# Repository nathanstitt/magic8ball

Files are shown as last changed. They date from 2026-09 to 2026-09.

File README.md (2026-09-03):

# Magic 8 Ball

Firmware for a physical, voice-activated **Magic 8 Ball** built on a round AMOLED
ESP32-S3 board. Ask it a question out loud — _"Magic 8 Ball, will it rain
tomorrow?"_ — and a glowing blue answer triangle rises from dark liquid, jitters
into place, blooms, and reveals an answer. The answer is generated live by
**Google Gemini** (which transcribes your spoken question and replies in five
words or fewer, in the oracular voice of a Magic 8 Ball). Tap or shake for a
classic random answer instead.

Everything is drawn by a **custom software renderer** — no LVGL, no GPU — a pure
RGB565 pixel pipeline running on the ESP32-S3.

## Hardware

- **Board:** [Waveshare ESP32-S3-Touch-AMOLED-1.75](https://www.waveshare.com/esp32-s3-touch-amoled-1.75.htm)
  ([documentation](https://docs.waveshare.com/ESP32-S3-Touch-AMOLED-1.75) — schematic, pinout, demos)
  - 466×466 round AMOLED, **CO5300** panel driven over QSPI
  - **QMI8658** 6-axis IMU (shake to ask)
  - **CST9217** capacitive touch (tap to ask, hold to factory-reset)
  - On-board microphone (**ES7210** codec) for wake word + question capture
  - **ES8311** codec + amplifier driving a speaker for the answer chime
  - **AXP2101** PMIC for power management, battery charging and fuel gauge
- **Microcontroller:** ESP32-S3 (dual-core Xtensa LX7, 8 MB PSRAM, 16 MB flash)

## Features

- **Voice-activated answers** — say the **"Magic 8 Ball"** wake word
  (on-device [microWakeWord](https://github.com/nathanstitt/micro_wake_word_standalone)
  model, ~61 KB), ask a question, and Gemini answers it in ≤5 words.
- **On-device wake-word detection** — runs locally; only the recorded question is
  sent to the cloud, and only after the wake word fires.
- **Record-until-silence** — an energy VAD ends recording when you stop talking,
  so asks are as short as your question.
- **One-shot multimodal Gemini call** — the recorded audio (WAV) and the persona
  prompt go to Gemini's `generateContent` in a single HTTPS request; Gemini both
  transcribes and answers.
- **Graceful fallback** — no Wi-Fi, no API key, or any API error falls back to one
  of the 20 classic Magic 8 Ball answers, so the ball always responds.
- **Tap & shake** — a screen tap or an IMU shake gives a classic random answer.
- **Animated reveal** — a 3-D triangle rises from the liquid, wobbles, blooms its
  glow, and the answer text fades in. The rise overlaps the Gemini round-trip
  (starts mid-wait, holds with a pulsing glow) to hide the latency.
- **Listening / thinking cues** — a white flitting starfield while it listens,
  switching to faster blue stars while Gemini is thinking.
- **Smart text layout** — a top-heavy best-fit word wrap fits answers to the
  apex-down triangle (more words on the wider upper rows).
- **Wi-Fi provisioning portal** — a captive-portal setup AP collects Wi-Fi
  credentials and the Gemini API key (stored in NVS); reachable at
  `http://magic8ball.local/` on the LAN, which also accepts custom messages via POST.
- **Hold-to-reset gesture** — hold the screen during normal use to clear saved
  Wi-Fi + API key and reboot into the setup AP (re-provision without a cable).
- **Answer chime** — three short blips play through the speaker as the answer
  blooms into view. Synthesized procedurally at boot (no audio asset): each blip
  glides down in pitch while the three step up, kept inside ~490–890 Hz because the
  ball's micro speaker has almost no output below ~450 Hz.
- **Power management** — sleeps the panel when idle, and runs a low-battery
  watchdog that powers the board down before the cell is damaged. Three guards must
  agree before it cuts power (boot grace period, a consecutive-low-reading streak,
  and a VBAT cross-check), because the fuel gauge reads a plausible-looking 0 for
  the first seconds after power-on.
- **Named on the network** — requests `magic8ball` as its DHCP hostname and
  advertises the same name over mDNS, so it is reachable at `magic8ball.local`
  (and often just `magic8ball`) rather than by a bare IP.

## Architecture (`main/`)

- `config.h` — every tunable (geometry, timing, colors, animation rates, mic gain).
  No magic literals elsewhere.
- `gfx/` — pure pixel primitives: framebuffer, color (RGB565 + blend), draw
  (rasterizer, triangle gradient + glow), text (Montserrat Bold). Host-testable.
- `scene/` — pure C logic: state machine
  (IDLE→SHAKING→TUMBLING→LOCKING→SHOWING→DISMISSING→SLEEP), animation, answers,
  the energy VAD, the listen FSM, and the bloop synthesizer. Host-testable.
- `render/` — `pyramid.cpp` (the 3-D triangle + glow, the only glm user), `fx.cpp`
  (background + starfield), `render.cpp` (compositor + text wrap).
- `hal/` — board drivers: display (CO5300), IMU, touch, mic, wake word, recorder,
  speaker (ES8311), power (AXP2101). Never compiled in host tests.
- `net/` — Wi-Fi (STA-with-AP-fallback), captive-portal provisioning, HTTP server,
  mDNS, the Gemini client, and the WAV/base64 helpers.
- `app_main.cpp` — dual-core split: core 0 = logic/events/voice, core 1 = render+flush.

The renderer does a full redraw each frame. The background is precomputed once and
memcpy'd per frame; identical scenes are skipped, so idle/showing cost nothing.

## Performance

The renderer is CPU-only (no GPU) and pushes the full 466×466 round panel over QSPI
every frame. Measured on the device during the answer animation
(build with `-DDEBUG_FPS` and `-DDEBUG_FLUSH_PROFILE` to log this):

| Phase | Frame rate | Render | Flush  |
|---|---:|---:|---:|
| Answer animation | ~12–16 fps | ~28–36 ms | ~32–35 ms |
| Idle / showing | ~0 (static frames skipped) | — | — |

- The **hard floor is the ~23 ms QSPI transfer** for one full frame; the flush
  measures ~32–35 ms including the byte-swap pipelined under DMA.
- Identical scenes are skipped via a `memcmp`, so IDLE and SHOWING render nothing —
  the AMOLED just holds the last flushed frame and the CPU stays idle.
- The animation only runs during SHAKING→TUMBLING→LOCKING; the expensive glow is
  deferred to the lock/bloom so the rise stays smooth.

Getting here took a dedicated optimization pass: rendering directly in the panel's
byte order (eliminating a 33 ms per-frame byte-swap), caching the circle-clip row
spans (31 ms → 5.5 ms), incremental edge functions + a ramp LUT in the triangle
gradient (135 ms → 57 ms), and flushing in cache-line-aligned strips with the
byte-swap pipelined under DMA.

## Enclosure

The 3-D printed enclosure lives in [`cad/`](cad/), designed in
[FreeCAD](https://www.freecad.org):

| File | What it is |
|---|---|
| `magic-8-ball.FCStd` | FreeCAD source — edit this |
| `magic-8-ball-Ball.stl` | The ball itself, 70 × 69.5 × 65 mm |
| `magic-8-ball-Base.stl` | The stand the ball sits in, 54 × 56 × 11 mm |

The STLs are exports of the FreeCAD document; regenerate them from the `.FCStd`
after any change rather than editing the meshes directly.

## Build / flash / test

Requires **ESP-IDF v5.5**. Source the toolchain first:

```bash
export IDF_PATH=/path/to/esp-idf-5.5
. "$IDF_PATH/export.sh"
```

**Firmware** (repo root, target esp32s3):

```bash
idf.py build
idf.py -p <PORT> flash monitor
```

The first configure needs network access (it fetches the Waveshare BSP, glm, and
the wake-word component).

**Host tests** (`host_test/`, linux target — runs the pure `gfx/`, `scene/`,
`render/`, and `net/` helpers under Unity):

```bash
cd host_test
idf.py build
printf '\n*\n' | ./build/magic8ball_host_test.elf
```

## First-time setup

1. Flash the firmware. On first boot (no saved credentials) the device starts a
   setup Wi-Fi AP named **`Magic-8-Ball-Setup`**.
2. Join that network; the captive portal opens. Enter your Wi-Fi name/password and
   your **Gemini API key** (from [Google AI Studio](https://aistudio.google.com)).
3. The device reboots, connects, and shows its IP. Say **"Magic 8 Ball"** and ask
   away.

To re-provision later, **hold the screen** during normal use until the reset
countdown completes — it clears the saved Wi-Fi + key and returns to the setup AP.

## Changing the wake word

The wake word is an on-device [microWakeWord](https://github.com/nathanstitt/micro_wake_word_standalone)
TFLite model embedded in the firmware (`main/hal/<phrase>_model.h`, wired up in
`main/hal/wakeword.cpp`). Swapping it is a two-part job:

**Train + install in one command** (local, Apple-Silicon GPU, no Google Colab):

```bash
cd wakeword-train
./make-wakeword.sh "Hey Oracle" --phonetic "hey or-uhkul" --install
```

That synthesizes samples with Piper TTS, augments + trains on MPS, exports the
quantized `.tflite`, wires it into `wakeword.cpp`, and builds the firmware. Then
`idf.py -p <PORT> flash monitor`, say the phrase, and tune `WW_PROBABILITY_CUTOFF`
on-device if needed. The `wakeword-train/` dir is gitignored; see its README for the
step-by-step scripts and the shared-dataset caveat (~33 GB, downloaded once).

To install a model you already have (community or pre-trained):

```bash
scripts/install-wake-word.sh <model.tflite> <model.json> "Phrase"
```

This generates the C header, wires the 4 tuning constants + the model symbol/label
into `wakeword.cpp`, and removes the old model.

## Notes

- The renderer never calls LVGL. The Waveshare BSP pulls LVGL in transitively as a
  build dependency, but our code uses a narrow software RGB565 pipeline.
- The wake-word component is GPLv3 (a standalone ESPHome-derived port); see
  `main/idf_component.yml`.

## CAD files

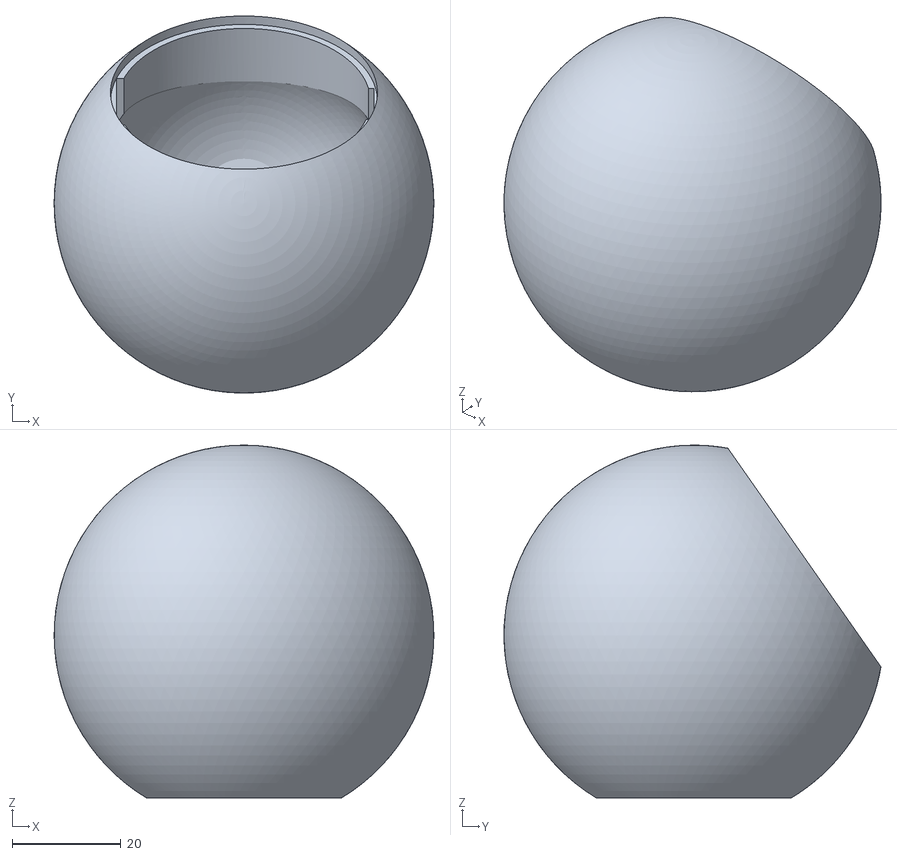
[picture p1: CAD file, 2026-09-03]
cad/magic-8-ball-Ball.stl
70.0 x 69.5 x 65.0

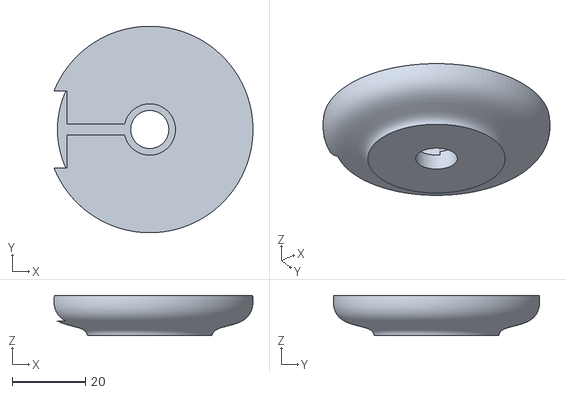
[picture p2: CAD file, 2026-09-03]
cad/magic-8-ball-Base.stl
54.2 x 56.2 x 11.0

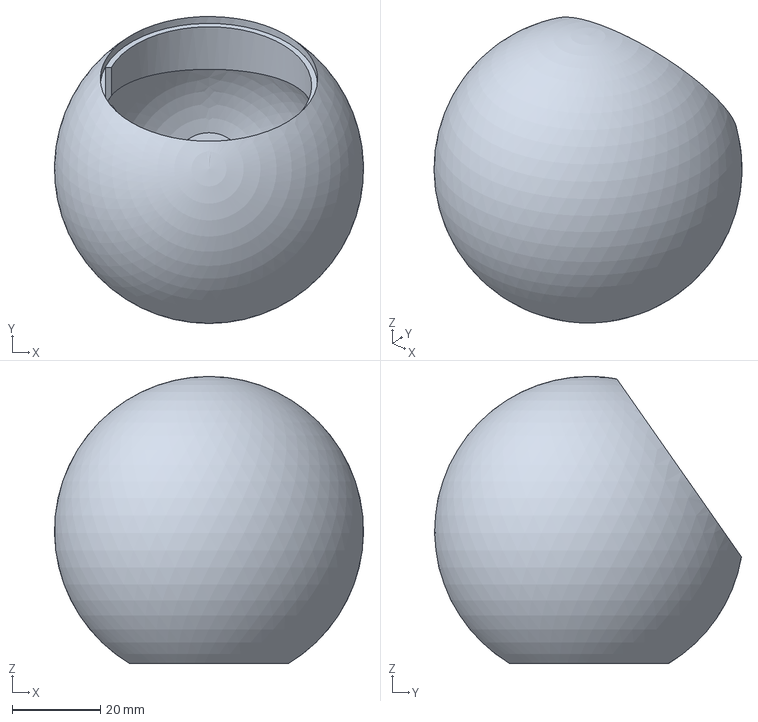
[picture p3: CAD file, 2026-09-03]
cad/magic-8-ball.FCStd
70.0 x 69.5 x 65.0 mm

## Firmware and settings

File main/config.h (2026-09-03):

#pragma once
#include <stdint.h>

// =============================================================================
// Magic 8 Ball — all tunable constants. Nothing is a magic literal elsewhere.
// =============================================================================

// --- Display geometry ---
#define DISP_W          466
#define DISP_H          466
#define DISP_CX         233
#define DISP_CY         233
#define DISP_RADIUS     233

// --- Frame rate ---
#define TARGET_FPS      30
#define FRAME_MS        (1000 / TARGET_FPS)

// --- Timing (ms) ---
// Per-tick animation-time cap. A blocking call (notably voice audio capture) can
// stall the logic loop; without this cap the next tick's dt would fast-forward
// the whole answer animation in one frame. 50ms = one frame at 20fps.
#define DT_MAX_MS           50
#define THINK_MIN_MS        1000
#define SHAKE_DEBOUNCE_MS   250
#define IDLE_SLEEP_MS       30000
#define TUMBLE_MS           1400    // ST_TUMBLING duration (rise + spin)
#define LOCK_MS             350     // ST_LOCKING duration (snap face-on, glow bloom, text fade)
#define DISMISS_MS          300     // ST_DISMISSING duration (fade the answer out)
#define SHOW_TIMEOUT_MS     90000   // auto-dismiss: after this long showing an answer, fade it out as if tapped

// --- Voice (wake word + VAD listening) -------------------------------------
// The micro_wake_word component is a one-shot wake detector: it fires once on the
// phrase and gives no ongoing post-wake speech signal. So the live flow is "wake
// -> ponder for PONDER_MS -> answer" (PONDER_MS path). The speech-based end
// (MIN_SPEECH_MS + SILENCE_MS) and the LISTEN_MAX_MS backstop remain for a future
// VAD source that supplies speech_active; they are dormant while it stays false.
#define MIC_SAMPLE_RATE_HZ  16000  // capture rate the wake-word model expects (16 kHz mono int16)
// Mic input gain (dB). The codec default captured speech at RMS ~15/32767 -- far too
// quiet for Gemini. Lift it substantially; tune from the recorder's rms log.
#define MIC_GAIN_DB         42.0f
#define PONDER_MS       3000   // wake ponder / in-flight voice ask window (tune on hardware)
// Hard cap on a voice ask (record + Gemini round-trip). If the voice task hasn't
// produced text by now, the logic loop reveals a random fallback. Chosen so a real
// answer about to land always beats this timer. Tune once real latency is known.
// Must exceed the true worst-case ask: REC_MAX_MS (8s record) + the Gemini HTTP
// timeout (15s) + margin. If this is shorter than a real ask, the ponder times out
// mid-ask and reveals a canned answer, then the real answer lands as a 2nd reveal.
#define VOICE_ASK_MAX_MS 25000

// --- Power / battery (AXP2101 PMIC) -----------------------------------------
// Charge params for the connected LiPo cell (<=500 mAh). Values are AXP2101
// register-field codes (see axp2101.h enums; kept as literals so config.h stays
// dependency-free): 0x09 = 300mA fast-charge CC (<=1C, safe for a small cell),
// 0x03 = 4.20V CV target.
#define BATT_CHARGE_CURRENT   0x09    // AXP2101_CHG_CURR_300MA
#define BATT_CHARGE_VOLTAGE   0x03    // AXP2101_CHG_VOLT_4V20
// Low-battery shutdown: poll the fuel gauge; at/below this SoC (and not on USB),
// show a warning for BATT_WARN_MS, then command the PMIC off. Polling every
// BATT_POLL_MS keeps the slow I2C read off the hot path.
#define BATT_LOW_PCT          15
#define BATT_WARN_MS          5000
#define BATT_POLL_MS          10000
// Shutdown guards. The AXP2101 fuel gauge (reg 0xA4) reads a plausible-looking 0
// for the first seconds after power-on, before it has settled -- taken at face
// value that reads as "0% -> shut down" and kills the board on every battery boot.
// Three independent guards, all of which must agree before we cut power:
//   - BATT_BOOT_GRACE_MS: ignore the gauge entirely this long after boot.
//   - BATT_LOW_STREAK: require N consecutive low polls, so one bad I2C read or
//     one transient gauge glitch can never trigger a shutdown on its own.
//   - BATT_MIN_MV: cross-check against the VBAT ADC. Above this the pack has real
//     charge left whatever the SoC byte claims, so the reading is not believed.
//     3600mV is well above the AXP2101's own undervoltage cutoff (the backstop
//     that protects the cell if this watchdog never fires at all).
#define BATT_BOOT_GRACE_MS    30000
#define BATT_LOW_STREAK       3
#define BATT_MIN_MV           3600
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

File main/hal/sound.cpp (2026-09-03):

#include "sound.h"
#include "config.h"
#include "scene/bloop.h"
#include "esp_log.h"
#include "esp_err.h"
#include "esp_heap_caps.h"
#include "esp_codec_dev.h"
#include "esp_codec_dev_types.h"
#include "freertos/FreeRTOS.h"
#include "freertos/task.h"

// The audio codec is driven through the Waveshare BSP. Those entry points are
// declared only in the LVGL-pulling umbrella header, so we forward-declare the
// narrow ones we need (matching the mic.cpp / imu.cpp / touch.cpp pattern). The
// esp_codec_dev headers are LVGL-free, so we include them directly. The
// i2s_std_config_t* arg of bsp_audio_init is passed as NULL (board defaults),
// so we declare it as const void * to avoid pulling the i2s header.
extern "C" esp_err_t bsp_i2c_init(void);
extern "C" esp_err_t bsp_audio_init(const void *i2s_config);
extern "C" esp_codec_dev_handle_t bsp_audio_codec_speaker_init(void);

static const char *TAG = "sound";
static esp_codec_dev_handle_t s_codec = NULL;
static TaskHandle_t s_task = NULL;
static int16_t *s_pcm = NULL;

// Set by the caller (logic core) before notifying, cleared by the audio task when
// playback finishes. Claiming it on the caller side closes the window between the
// notify and the task actually being scheduled. There is exactly one writer of
// `true` (the logic core) and one writer of `false` (the audio task), so there is
// no read-modify-write race and a plain volatile bool is sufficient.
static volatile bool s_playing = false;

static void task_sound(void *arg)
{
    (void)arg;
    while (true) {
        ulTaskNotifyTake(pdTRUE, portMAX_DELAY);

        // Always close first. esp_codec_dev_open() early-returns OK if the device
        // believes it is already open, so a previously half-failed open (opened
        // flag set, format rejected) would otherwise wedge us silent forever.
        // close() on an already-closed device is a no-op.
        esp_codec_dev_close(s_codec);

        // Must match the mic's format EXACTLY. The two codecs share one I2S
        // peripheral: esp_codec_dev compares this against the open input and
        // returns ESP_CODEC_DEV_NOT_SUPPORT on a sample-rate mismatch, and a
        // channel/bit mismatch would push it down a path that reconfigures --
        // i.e. interrupts -- the running mic.
        esp_codec_dev_sample_info_t fs = {};
        fs.bits_per_sample = 16;
        fs.channel = 1;
        fs.channel_mask = 0;
        fs.sample_rate = BLOOP_SAMPLE_RATE_HZ;
        fs.mclk_multiple = 0;

        int ret = esp_codec_dev_open(s_codec, &fs);
        if (ret != ESP_CODEC_DEV_OK) {
            // Not fatal and not latched: a later reveal retries. No log throttle
            // needed -- the FSM already rate-limits this to once per answer.
            ESP_LOGW(TAG, "speaker open failed: %d (silent this time)", ret);
            s_playing = false;
            continue;
        }

        // A fresh handle's stored volume is 0, which esp_codec_dev maps to -96 dB.
        // Without this the writes below are inaudible. The ES8311 has a hardware
        // volume register, so this is a register write and our buffer is untouched.
        esp_codec_dev_set_out_vol(s_codec, BLOOP_VOLUME_PCT);

        for (size_t off = 0; off < BLOOP_TOTAL_SAMPLES; off += SOUND_WRITE_CHUNK) {
            size_t n = BLOOP_TOTAL_SAMPLES - off;
            if (n > SOUND_WRITE_CHUNK) {
                n = SOUND_WRITE_CHUNK;
            }
            if (esp_codec_dev_write(s_codec, s_pcm + off,
                                    (int)(n * sizeof(int16_t))) != ESP_CODEC_DEV_OK) {
                ESP_LOGW(TAG, "speaker write failed; truncating bloop");
                break;
            }
        }

        // esp_codec_dev_write returns once the data is QUEUED to DMA, not once it
        // has been played, so closing immediately would cut off the tail.
        vTaskDelay(pdMS_TO_TICKS(SOUND_DRAIN_MS));

        // Closing drops the power amp (the ES8311 driver owns that GPIO), which is
        // why we open and close per play rather than holding the codec open: this
        // device idles almost all the time, and a continuously powered class-D amp
        // on a micro speaker hisses audibly in a quiet room. If the amp's turn-on
        // transient ever proves worse than the hiss, the alternative is to stay
        // open and esp_codec_dev_set_out_mute() while idle.
        esp_codec_dev_close(s_codec);
        s_playing = false;
    }
}

int sound_init(void)
{
    // Same idempotent bring-up mic.cpp does. Both calls are no-ops if the display
    // (I2C) or the mic (I2S) already ran them, but doing them here means the
    // speaker still works on a board where the wake-word mic never came up -- in
    // that case nothing else has called bsp_audio_init at all.
    esp_err_t err = bsp_i2c_init();
    if (err != ESP_OK && err != ESP_ERR_INVALID_STATE) {
        ESP_LOGE(TAG, "bsp_i2c_init failed: %s", esp_err_to_name(err));
        return -1;
    }
    err = bsp_audio_init(NULL);
    if (err != ESP_OK && err != ESP_ERR_INVALID_STATE) {
        ESP_LOGE(TAG, "bsp_audio_init failed: %s", esp_err_to_name(err));
        return -1;
    }

    s_codec = bsp_audio_codec_speaker_init();
    if (s_codec == NULL) {
        ESP_LOGE(TAG, "bsp_audio_codec_speaker_init returned NULL");
        return -1;
    }

    // Internal RAM, not PSRAM: I2S DMA reads straight out of this buffer, and
    // internal RAM sidesteps the cache-coherency dance the display flush needs.
    // At ~14KB it is well under CONFIG_SPIRAM_MALLOC_ALWAYSINTERNAL anyway; the
    // explicit caps just make that independent of the threshold.
    s_pcm = (int16_t *)heap_caps_malloc(BLOOP_TOTAL_SAMPLES * sizeof(int16_t),
                                        MALLOC_CAP_INTERNAL | MALLOC_CAP_8BIT);
    if (s_pcm == NULL) {
        ESP_LOGE(TAG, "OOM rendering bloop (%d bytes)",
                 (int)(BLOOP_TOTAL_SAMPLES * sizeof(int16_t)));
        s_codec = NULL;
        return -1;
    }

    // Rendered once: the cue is deterministic, so the play path stays a bare
    // write with no arithmetic and no allocation.
    size_t n = bloop_render(s_pcm, BLOOP_TOTAL_SAMPLES);
    if (n != BLOOP_TOTAL_SAMPLES) {
        ESP_LOGE(TAG, "bloop_render wrote %d of %d samples",
                 (int)n, (int)BLOOP_TOTAL_SAMPLES);
        heap_caps_free(s_pcm);
        s_pcm = NULL;
        s_codec = NULL;
        return -1;
    }

    if (xTaskCreatePinnedToCore(task_sound, "sound", SOUND_TASK_STACK, NULL,
                                SOUND_TASK_PRIO, &s_task, SOUND_TASK_CORE) != pdPASS) {
        ESP_LOGE(TAG, "sound task create failed");
        heap_caps_free(s_pcm);
        s_pcm = NULL;
        s_codec = NULL;
        s_task = NULL;
        return -1;
    }

    ESP_LOGI(TAG, "speaker ready (%d Hz, %d blips, %d ms, vol %d%%)",
             BLOOP_SAMPLE_RATE_HZ, BLOOP_COUNT,
             BLOOP_COUNT * (BLOOP_BLIP_MS + BLOOP_GAP_MS), BLOOP_VOLUME_PCT);
    return 0;
}
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

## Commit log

2026-06-18 Magic 8 Ball firmware: 3D tetrahedron rewrite, no LVGL
    Pure software RGB565 renderer for the Waveshare ESP32-S3-Touch-AMOLED-1.75.
    Shake/tap raises a glowing tetrahedron that tumbles in 3D, locks face-on, and
    reveals one of the classic 20 answers.
    - gfx/: framebuffer, color, rasterizer (64-bit scanline fill + lit triangle), text
    - scene/: state machine, animation (column-major mat3, no glm), answers
    - render/: pyramid.cpp (glm 3D core), fx.cpp, render.cpp compositor
    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
2026-06-18 Fix on-device HAL: direct CST9217 init + strip-based display flush
    On-hardware bring-up surfaced two issues:
    - BSP 3.0.0 bsp_touch_new() asserts cfg != NULL and reads it as a
    bsp_display_cfg_t (an LVGL-port struct), which would force pulling LVGL.
    Initialize the CST9217 directly via esp_lcd_touch_new_i2c_cst9217 instead,
    reusing the shared I2C bus. Stays LVGL-free; touch confirmed working.
    - A full-frame 434KB QSPI transfer exhausts the SPI DMA descriptor pool
    (ESP_ERR_NO_MEM). Flush in 8 horizontal strips, each its own async transfer
    with a DMA-done wait. Display now refreshes cleanly with zero errors.
    Verified on the board: display, QMI8658 IMU (5/5 boots), and touch all init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
    [touch.cpp]
2026-06-18 Fix display color order and PSRAM cache-coherency corruption
    Two on-device display bugs, both now verified fixed on the panel:
    - Colors were wildly wrong (green bg, cyan triangle): the CO5300 over QSPI
    expects big-endian RGB565 but our framebuffer is native little-endian. Byte-
    swap each pixel in the flush (the BSP's own LVGL path does the same via
    lv_draw_sw_rgb565_swap).
    - Diagonal corruption streaks: the CPU-side byte swap left dirty cache lines
    that DMA read stale. Allocate framebuffers 32B cache-aligned, keep each strip
    start cache-aligned (8 rows = 7456B = 233*32), and esp_cache_msync(C2M) each
    strip before draw_bitmap. Requires the esp_mm component.
    Also dropped the red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
2026-06-18 Reshape the answer die: symmetric triangle, radial glow, smooth bloom
    Visual pass to match the real Magic 8 Ball reference:
    - Triangle is now a clean symmetric apex-down die, not a real tetrahedron face
    (whose corners projected unevenly and looked tilted vs the level text).
    pyramid.cpp draws 3 coplanar verts; the gentle wobble is a small 3D lean that
    settles perfectly symmetric when locked.
    - Filled with a radial gradient (bright near-white-blue center -> bright blue
    edge) via the new draw_triangle_gradient; the edge stays bright so it melts
    into the glow with no dark seam. Bevel sheen off.
    - Smooth outer bloom via the new draw_triangle_glow: a single continuous
    per-pixel distan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
    [config.h]
2026-06-18 Optimize render performance: precompute, skip static frames, defer glow
    The animation ran at ~2 FPS. Profiling (render vs flush, per state) drove these:
    - Background was ~527ms/frame from a per-pixel sqrtf over the whole circle
    (gradient + halo). Bake the full gradient+halo once into a PSRAM buffer at
    fx_init(); the per-frame background is now a memcpy (~no compute). The
    murk-driven halo brightening is dropped (baked at a fixed strength) for speed.
    - Skip rendering entirely when the scene is unchanged from the last drawn frame
    (memcmp). The AMOLED holds the last image, so IDLE/SHOWING cost nothing.
    Particles are frozen outside the active states so those frames are static.
    - Defer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
    [config.h]
2026-06-18 Pipeline byte-swap under DMA in display flush
    Flush was ~63ms/frame: ~27ms CPU byte-swap+cache-sync + ~23ms QSPI DMA wait,
    run serially per strip. Restructure to keep one strip's DMA in flight while the
    CPU prepares (swaps + msyncs) the next strip, hiding most of the swap under the
    transfer. Flush drops ~63ms -> ~39ms, raising the frame ceiling (cheapest frame
    ~110ms -> ~86ms). Strips are non-overlapping y-bands so swapping the next strip
    during the current strip's DMA is safe; per-strip cache alignment + msync-before-
    its-own-DMA are preserved. Verified clean on-device (no corruption/tearing).
2026-06-18 Animate the answer arrival: random entry, jitter, grow-in, early glow
    The die used to rise straight up from the bottom and glide to center. Now each
    ask animates more like a real 8-ball bobbing up through liquid:
    - Random entry direction: on each ask the state machine picks a random angle
    (hardware RNG) and seeds an off-screen start point; the die slides in from
    that edge toward center (scene.pyr_start_x/y).
    - Positional jitter: a two-frequency positional shimmy (JITTER_AMP, per-ask
    phase) that damps to zero as it settles dead-center, so it jostles in rather
    than gliding.
    - Grow-in: pyr_scale eases from TUMBLE_SCALE_START (0.15) to 1.0 over the rise,
    so the die grows from small/di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
    [config.h, test_animation.c]
2026-06-18 Review hardening: assert strip alignment, document static-skip, drop IMU sqrt
    Follow-ups from a correctness/efficiency review:
    - display.cpp: static_assert that a full flush strip is an exact multiple of the
    cache line. The pipelined flush's safety depends on it (else prepare_strip's
    rounded-up esp_cache_msync would spill into the next, not-yet-swapped strip
    during its DMA). Documents + enforces the load-bearing invariant.
    - app_main.cpp: document why the bytewise scene memcmp (floats + padding) is
    safe — all writes flow through memcpy, static states re-assign identical
    constants, and it fails safe (spurious render, never a missed update).
    - imu.cpp: imu_is_shaking() now compare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
    [imu.cpp]
2026-06-18 Add WiFi, captive portal, and HTTP POST message listener
    Network-connect the ball: on boot try saved STA creds, else bring up a
    SoftAP + captive portal (DNS catch-all to a config form, saved in NVS).
    Once on the LAN, POST text to /message (or http://magic8ball.local via
    mDNS) to animate a custom message with the existing rise/bloom/show.
    Verified on hardware: STA connect, mDNS, POST (direct + mDNS), non-ASCII
    sanitizing, latest-wins, empty-body rejection, and the AP/portal path.
    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
    [partitions.csv]
2026-06-18 Hide the Wi-Fi status overlay after the first answer is shown
    The on-screen IP / setup hint is only useful until the device has shown
    its first answer; latch on the first ST_SHOWING and stop publishing the
    status line so the IP no longer clutters the scene afterward.
2026-06-19 test(scene): re-arm and stray-speech guards for listen FSM
2026-06-19 feat(scene): fixed-ponder timeout for one-shot wake (no post-wake VAD)
    [config.h]
2026-06-19 build: point micro_wake_word at fork with esp32s3 crc fix
2026-06-19 feat: replace listening swirl with flitting blue starfield
    The per-pixel swirl rendered at ~257ms/frame even after LUT+downsampling
    (it computes trig for every pixel). Replace it with a starfield: re-task the
    existing particles to flit in random directions and render as brighter blue
    2x2 stars while listening. Cost is ~N point writes/frame, trivially 30fps.
    Also adds a dt_ms clamp (DT_MAX_MS) so a slow voice-capture tick can't
    fast-forward the whole answer animation in one frame.
    [config.h]
2026-06-19 feat: vary star sizes (half 4x4, half 2x2) and fade starfield out as answer rises
    Half the listening stars now render at 4x4, half at 2x2, for size variety.
    The starfield no longer pops out when the triangle floats in: app_main ramps
    a star_fade (0..255) down over STAR_FADE_MS once listening ends, so the stars
    dissolve across the answer's rise instead of vanishing on the state change.
    [config.h]
2026-06-19 perf(display): instrument flush to split byte-swap vs DMA-wait time
    Profiling (-DDEBUG_FLUSH_PROFILE) revealed the ~45ms flush is ~33ms CPU
    byte-swap of the PSRAM framebuffer and only ~0.7ms DMA wait. Raising QSPI
    to 80MHz changed nothing, confirming the transfer is not the bottleneck -
    the per-frame in-place byte-swap over slow PSRAM is. Instrumentation kept
    behind the existing DEBUG_FLUSH_PROFILE flag for future tuning.
2026-06-19 perf(display): byte-swap into SRAM bounce buffers instead of in-place PSRAM
    Measured: the per-frame flush byte-swap dropped from ~33ms to ~25ms by swapping
    each strip from the PSRAM framebuffer into a DMA-capable internal-SRAM bounce
    buffer (ping-ponged so the in-flight DMA's source is never clobbered) instead of
    an in-place read-modify-write over slow PSRAM. Also drops the per-strip
    esp_cache_msync (internal SRAM is DMA-coherent). The remaining ~25ms is the
    unavoidable PSRAM read of the 434KB frame; eliminating that needs rendering in
    pre-swapped byte order (next).
2026-06-19 perf(gfx): render directly in panel byte order; flush no longer byte-swaps
    The framebuffer now stores RGB565 in the CO5300's big-endian byte order: every
    pixel is packed via fb_pack at the gfx-layer store boundary (fb_set_px, the
    blends in draw/text, the fx_init background bake) and unpacked via fb_unpack on
    read-back for blending. Color math in color.h is untouched and stays native.
    This removes the entire per-frame byte-swap pass: the measured flush byte-swap
    dropped from ~33ms to ~0 (prepare_strip is now a plain memcpy). Animation is
    visibly smoother and colors verified correct on-device. The DMA transfer (~13ms)
    is now the visible cost. All 85 host tests pass (the one storage-order test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
2026-06-19 perf(gfx): cache circle-clip row spans; add render-stage profiling
    draw_circle_clip swept all 217k pixels with a per-pixel distance multiply every
    frame to mask a STATIC round-display corner region (~31ms measured, incl. the
    glass arc). Now it caches the inside-circle x-span per row (one sqrt per row,
    rebuilt only if geometry changes) and zeroes just the outside corner pixels:
    arc+clip dropped to ~5.5ms, and steady SHAKING render fell from ~55ms to ~30ms
    (fps ~9 -> ~12). Both circle-clip host tests still pass (exact rim preserved).
    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
2026-06-19 perf(gfx): incremental edge functions + ramp LUT in triangle gradient
    The radial die fill (draw_triangle_gradient) is the per-frame hot path during the
    answer rise. Two changes, both validated by the existing gradient host tests:
    - Incremental edge functions: the 3 barycentric edge values are linear in x/y, so
    compute them once per row and step by a constant per pixel instead of 3 full
    edge_fn() calls (~9 multiplies) every pixel. Bit-exact (same integer math).
    - Radial fill via a 256-entry edge->center ramp LUT (cached, rebuilt only when the
    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
2026-06-19 fix(render): center answer text adaptively by line count
    The text block was centered at a fixed y=196, sitting too high in the apex-down
    triangle. Now it centers at the triangle centroid / screen center (~233) so 1-3
    line answers look balanced, and only shifts up if a tall 4-line block would push
    its bottom past TEXT_MAX_BOTTOM_Y (where the triangle has narrowed too much).
    All text-layout host tests still pass.
    [config.h]
2026-06-19 feat(hal): switch wake word to 'Hello Computer'
    Replace the Hey Jarvis model with the community-trained hello_computer model
    (github.com/TaterTotterson/microWakeWords, V3; embedded as hello_computer_model.h)
    and its published tuning (probability_cutoff 0.53, sliding_window 3, arena ~36KB).
    Verified loading on device. Removes hey_jarvis_model.h.
2026-06-19 feat(scene): pure energy-VAD endpointer (host-tested)
    Fix PONDER_MS (10000 → 3000) so ponder path fires before LISTEN_MAX_MS (8000).
    [config.h]
2026-06-19 feat(hal): gate wake-word re-arm so the recorder can own the mic
2026-06-19 feat: voice task — record, ask Gemini, inject answer (fallback to classic)
2026-06-19 feat: hold-screen-at-boot factory reset (clear Wi-Fi + API key -> setup AP)
    [config.h, touch.cpp]
2026-06-19 feat: factory reset via hold-screen gesture during normal use
    Replaces the boot-time hold (which couldn't catch the press reliably and
    needed a replug) with a runtime gesture: hold the screen ~1s to show a
    'KEEP HOLDING / RESET IN N...' countdown, held to RESET_HOLD_MS total it
    clears Wi-Fi + API key and reboots into the setup AP. Release cancels.
    The logic loop owns the panel during the overlay (s_reset_overlay backs
    off the render task); on release s_force_render restores the scene past
    the render static-frame cache. Countdown redraws only on second-change to
    avoid saturating the loop with full-frame flushes.
    [config.h]
2026-06-19 fix(hal): raise mic input gain (codec default captured speech at RMS ~15)
    At default gain speech was inaudible to Gemini (generic 'ask again' answers, VAD
    never endpointed). Set MIC_GAIN_DB on the codec; recording now stops on silence and
    Gemini transcribes the question.
    [mic.cpp]
2026-06-20 feat: overlap triangle rise with the Gemini wait + UX tunables
    Voice latency overlap: at SUBMIT_RISE_DELAY_MS (3s) into the ~5.5s round-trip, start
    the triangle rising BLANK (sm_start_pending_rise -> TUMBLING with text_pending). It
    locks face-on and HOLDS with a pulsing glow until the answer lands, then the text
    fades in (sm_set_pending_text). Hides most of the wait behind the rise. Non-voice
    paths (tap/shake/POST) keep the text-ready-before-rise behavior.
    Also bundled (shared config.h/app_main.cpp):
    - larger answer triangle (PYRAMID_RADIUS 196->245) so tips extend past the screen
    - post-answer shake cooldown (SHOW_SHAKE_COOLDOWN_MS 10s) so reading can't re-ask
    - star color swap: white whil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
    [config.h]
2026-06-20 docs: add README (device, features, architecture, FPS/performance, setup)
2026-09-03 fix: guard the low-battery shutdown against bogus gauge reads
    The AXP2101 fuel gauge (reg 0xA4) reads a plausible-looking 0 for the first
    seconds after power-on, before it has settled. Taken at face value that reads as
    "0% -> shut down", which killed the board on every battery boot.
    Require three independent guards to agree before cutting power: ignore the gauge
    for BATT_BOOT_GRACE_MS after boot, require BATT_LOW_STREAK consecutive low polls
    so a single bad I2C read can never trigger it, and cross-check the VBAT ADC
    against BATT_MIN_MV.
    Also gate on VBUS presence rather than charge phase (power_is_vbus_present),
    since "charging" goes false at charge-done while still on USB, and switch
    powe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
    [config.h, power.cpp]
2026-09-03 feat: play a three-note bloop when the answer is revealed
    A speaker is now connected, so the answer reveal gets an audio payoff. Three
    short sine blips, each gliding down in pitch (the glide is what reads as "bloop"
    rather than "beep") while successive blips step up, so the gesture as a whole
    rises. Synthesized procedurally -- no WAV asset, no decoder, ~14KB of PCM
    rendered once at boot.
    Split the way scene/vad.c and hal/recorder.cpp already are: scene/bloop.c is pure
    C and host-tested; hal/sound.cpp owns the codec handle and the playback task.
    Two hardware constraints shaped this:
    - The ES8311 speaker and ES7210 mic share one I2S peripheral, and esp_codec_dev
    rejects an output open who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
    [config.h, sound.cpp]
2026-09-03 feat: request "magic8ball" as the DHCP hostname
    The device asked for a lease anonymously, so it showed up in the router's client
    list as "espressif" or a bare MAC. Set the hostname on the STA netif before
    Wi-Fi starts -- DHCP option 12 rides along with the lease request, so setting it
    afterwards has no effect on the already-sent request.
    On a router that registers DHCP names in local DNS this also makes the bare
    "magic8ball" resolve, not just magic8ball.local via mDNS.
    Move the name into net.h as NET_HOSTNAME. It was a private define in net.cpp used
    only for mDNS; wifi.cpp now needs the same string for DHCP, and two literals
    would be free to drift apart.
2026-09-03 docs: add the enclosure CAD and correct the README
    Add the FreeCAD source and the two STL exports (ball + base) under cad/, and
    document them in a new Enclosure section with their printed dimensions.
    Correct several things the README got wrong:
    - The wake word is "Magic 8 Ball", not "Hello Computer" (see the label passed to
    add_wake_word_model in hal/wakeword.cpp). It was wrong in three places.
    - The model is ~61 KB, not ~36 KB, counting the bytes in the embedded array.
    - The board has 8 MB PSRAM; 16 MB is the flash. The two were conflated.
    - The state machine list omitted ST_DISMISSING.
    Also document what had been added but never written up: the answer chime, the
    low-battery watchdog,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
    [magic-8-ball-Ball.stl, magic-8-ball-Base.stl, magic-8-ball.FCStd]
2026-09-03 docs: link the Waveshare board documentation
    The board entry linked only the store page. Add the docs wiki alongside it, which
    is where the schematic and pinout live -- the useful reference when working out
    which peripheral is on which GPIO.
2026-09-04 fix: add the missing digit glyphs, and count spaces when measuring text
    Posting "8 Ball is Magic" to the device rendered " Ball is Magic". The font had
    no glyphs for 0-9 at all -- only A-Z, a-z and !',-.? -- and text_mb_draw()
    silently advances past a codepoint it cannot render, so a digit vanished with no
    error anywhere. Any Gemini answer or custom message containing a number was
    quietly losing it.
    Regenerate the header from the upstream Montserrat TTF with the digits included,
    and add scripts/gen-font.py so the character set is a visible, reproducible
    decision rather than a committed blob nobody can regenerate -- which is how it
    came to be missing the digits in the first place. The script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
